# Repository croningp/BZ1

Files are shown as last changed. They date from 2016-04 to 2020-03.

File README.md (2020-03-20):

# BZ-CA

Platform to physically embody cellular-automaton using Belousov-Zhabotinsky
reaction-diffusion chemistry in addressably stirred cells.

## Aims of project
* Create working platform of addressable magnetic stirrers
* Use platform to demonstrate control over cell oscillations
* Control patterns of oscillating cell arrays using machine learning

## Platform
BZ-CA has a working stirrer array. It is also connected to a series of pump to add/remove liquid.

How to build the platform is explained with detail on the manuscript [pre-print](https://chemrxiv.org/articles/A_programmable_chemical_computer_with_memory_and_pattern_recognition/7712564).  

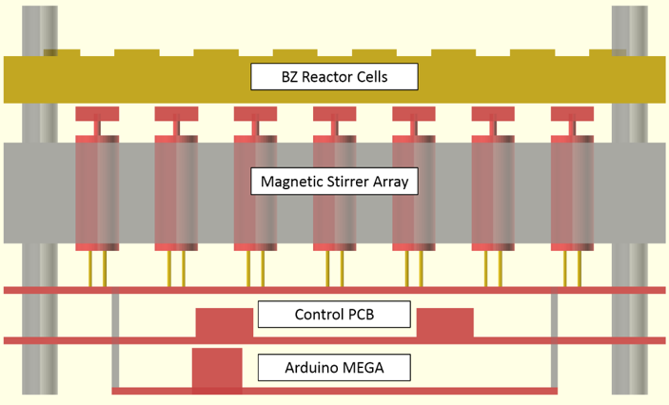
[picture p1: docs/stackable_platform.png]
stackable_platform


This document explains how to build the first iteration of the platform, which is what was used to obtain the results obtained there.
It used custom-made electronics.
The current iteration uses the same hardware and 3D-printed parts, but the electronics are controlled using stacked [Adafruit Motor shields](https://learn.adafruit.com/adafruit-motor-shield-v2-for-arduino).

## Software

The software to control this platform is divided into different files:

* [bzboard.py](software/bzboard/bzboard.py) controls the motors that actuate the stirrers.
* [pumpsctl.py](software/pumpsctl/pumpsctl.py) controls the pumps to add and remove liquid from the platform.
* [firmware](software/firmware/) controls the Arduino scripts to control the 2 arduinos that were actuating the stirrers and the pumps.
* [image processing](software/img_proc) is the implementation of the SVM to classify the oscillations between red and blue.

## Example Code
An example of how to use the bzboard.py code is provided below
and in [initBZ.py](software/initBZ.py):

```python

################################################################
# This script should be used before starting the experiments
# to make sure everything is working and tubes are filled
################################################################

import time

from pumpsctl.pumpsctl import PumpsCtl
from bzboard.bzboard import BZBoard
from img_proc.record_cam import RecordVideo
import os, sys
sys.path.append(os.path.abspath('..'))
from tools.volctl import VolCtl 

v = VolCtl()
b = BZBoard("/dev/ttyACM1")
p = PumpsCtl('/dev/ttyACM0', v)

rv = RecordVideo(10)

waste = {'pump':'P0', 'quantity':75, 'speedIn':50, 'speedOut':50}
water = {'pump':'P4', 'quantity':5, 'speedIn':60, 'speedOut':70}
h2so4 = {'pump':'P2', 'quantity':5, 'speedIn':60, 'speedOut':70}
kbro3 = {'pump':'P5', 'quantity':5, 'speedIn':110, 'speedOut':110}
malonic = {'pump':'P3', 'quantity':5, 'speedIn':60, 'speedOut':70}
water_clean = {'pump':'P4', 'quantity':50, 'speedIn':50, 'speedOut':70}
ferroin = {'pump':'P1', 'quantity':2, 'speedIn':50, 'speedOut':50}

# make sure these 4 pumps are filled, I will test ferroin individually 
p.pump_multiple(water, malonic, kbro3, h2so4,ferroin)
# activate all max speed for 30 second to mix
b.activate_all()
time.sleep(30)
b.disable_all()

rv.record_threaded("test")
time.sleep(10)

p.pump_multiple(water_clean, waste)
p.pump_multiple(waste)
```

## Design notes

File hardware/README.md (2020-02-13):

This folder contains all the designs and stl files of the 3D-printed parts.

All of them were designed with OpenSCAD and printed using a Stratasys Connex 3D-printer, with white material.

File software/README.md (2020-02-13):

This folder contains all the software written to develop this project.

* bzboard contains the python script to actuate as middleman between the firmware and the stirrers. This is the one used by the user to perform experiments.
* pumpsctl is a similar file to bzboard, but in this case to control the liquid pumps.
* img_proc contains all the files used to perform the Computer Vision using a SVM and classify the oscillations between red and blue.
* tools contains two files, one of them to send emails from the platform when a message needs to be sent, and another one to check the volume of the different reactants and the waste bottle.
* firmware contains the Arduino-C code to control both the pumps and the stirrers. 2 different Arduino Mega boards were used, one for each.
* Data Analysis contains a Jupyter Notebook to analyse the dataset used to train the SVM.

All the other python files in this folder were used to directly run experiments.

* initBZ.py should be executed before starting the experiments. It's objective is to check that everything works fine. This must be visually inspected by the user, this script will merely run quickly all the components.
* cleanBZ.py is a script used to clean the area with waste and water.
* main.py is a basic script which will load the BZ medium into the platform, and then drain in. Code here can be injected to execute one experiments.
* automatedBZ.py is the script we used the most, and it will perform all the steps required to perform one experiment.
* experiment_parent.py and randompatter.py are OO implementations of the previous one.
* cellular_automata.py is an attempt of creating a CA using this platform, and it can be used to dynamically actuate the motors based on the visual information from the image processing. Nevertheless, the CA never really worked on this iteration of the platform.

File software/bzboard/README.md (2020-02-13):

bzplatform is the python script to communicate with the arduino and actuate the platform.

in the "patterns" folder there it can be seen all the patterns that we use to input data into our platform.

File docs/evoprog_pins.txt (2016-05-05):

evopin:[pwmshield,pwmpin]
 2:[1, 7]
 3:[1, 6]
 4:[1, 5]
 5:[1, 4]
 6:[1, 3]
 7:[1, 2]
 8:[1, 1]
 9:[1, 0]
14:[0, 4]
15:[0, 5]
16:[0, 6]
17:[0, 7]
24:[0, 8]
26:[0, 9]
28:[0,10]
30:[0,11]
32:[0,12]
34:[0,13]
36:[0,14]
38:[0,15]
42:[1, 8]
44:[1, 9]
46:[1,10]
48:[1,11]
50:[1,12]
52:[1,14]
53:[1,15]
51:[1,13]

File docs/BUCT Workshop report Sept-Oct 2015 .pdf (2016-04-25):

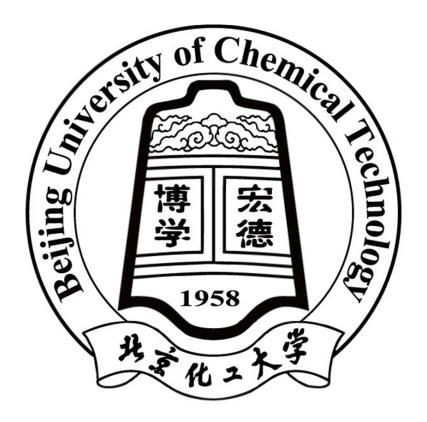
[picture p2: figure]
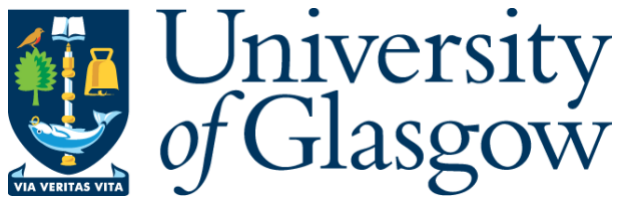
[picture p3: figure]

# Coupling Belousov–Zhabotinsky Oscillations in 3D Reactionware

# October 2015 WORKSHOP REPORT

PREPARED BY

Dr. Geoff Cooper
Kevin Donkers

## Acknowledgements

### Organizers and Participants

Organizers:

■ | School of Chemistry, University of Glasgow, United Kingdom;
■ | International Research Centre for Soft Matter, Beijing University of Chemical Technology, China;
■ | State Key Laboratory of Chemical Resource Engineering, Beijing University of Chemical Technology, China

Moderators:

■ | Prof. Leroy Cronin, University of Glasgow;
■ | Prof. Yu-Fei Song, Beijing University of Chemical Technology

Participants:

Dr. Geoff Cooper, Kevin Donkers, Dr. Chang-Gen Lin, Ze-lin Wang, Wei Zhou, Wen-bo Zhang and Xue-ting Xiong.

## Table of Contents

# Introduction

Three-dimensional (3D) printing (or Additive Manufacturing), which has been widely used in industrial manufacturing to produce prototypes,¹ has gained increasing momentum and popularity over the past decade in various fields such as medicine,² biology,³⁻⁵ millifluidics/microfluidics,⁶⁻⁸ electronics,

9 and pneumatics.¹⁰⁻¹² The key advantage of 3D printing lies in its ease, speed and price of design and manufacturing compared to commercial alternatives. Recently the concept of 3D-printed bespoke reactors, or “reactionware”, for chemical science has been proposed by Cronin et al.¹³⁻ 15 Another advantage of 3D printing is that the designs for a product can be shared online, downloaded, modified and then rapidly reproduced to meet personal demand.

The Belousov-Zhabotinskii (BZ) reaction is one of the most well-known and widely studied oscillating chemical reactions. Although it was first reported in 1958 by B. P. Belousov,¹⁶ it was not widely accepted by the scientific community until the early sixties when more detailed studies had been completed by A. M. Zhabotinskii.¹⁷ The first oscillating reactions of this type were produced by the addition of potassium bromate and citric acid to an acidified solution of cerium IV sulphate. After a short induction period, oscillations in intermediate concentrations are produced by autocatalytic single electron redox reactions involving the metal ion catalyst. The colour of the solution is seen to alternate between clear and pale yellow with a period of a few minutes. This oscillatory behaviour is sustained for several hours during which the substrate, citric acid, is decomposed to produce methanoic acid and carbon dioxide gas. Although all known BZ type oscillating reactions involve potassium bromate as the oxidising agent, the use of several different metal-ion catalysts, organic substrates and acids have been investigated.¹⁸ Oscillations have been successfully obtained using various free metal ions or their complexes, all of which have a single electron couple with a reduction potential of around +1.5 V / SHE.¹⁸

In order to allow visual observation of the oscillations, Fe(phen)2

2+ (ferroin) is often
added to the reaction mixture (or even used as the main metal catalyst) as it has a strong red colouration but is bright blue in its oxidised form, ferrin. There is also a large range of organic substrates that give rise to oscillations in this system, although malonic acid (MA) is the most widely used. The mechanistic details of the cerium catalysed BZ reaction of malonic acid were elucidated in 1972 by Field, Kõrõs and Noyes¹⁹ and supplied an intellectual framework for further investigation of this system. The skeleton FKN mechanism (so named after its discoverers) comprises eleven discrete reactions, but for a general mechanistic description, it is often more useful to simplify the FKN mechanism to a three step sequence often referred to as the Simple Oregonator Model (SOM):
{A} | BrO3
- + 2Br⁻ + 3CH2(COOH)2 + 3H⁺ | 3BrCH(COOH)2 + 3H2O
{B} | 4M⁽x) + BrO3
- + 5H⁺ + CH2(COOH)2 | 4M⁽x+1) + 3H2O + BrCH(COOH)2

{C} | BrCH(COOH)2 + 4M⁽x+1) + 2H2O | 5H⁺ + Br⁻ + 4M⁽x) + 2CO2 + HCOOH

The oscillations of the BZ reaction are sensitive to external physical perturbations and may become complex or show chaotic behaviour under some situations. For example, the period of oscillation is known to vary with temperature.

20 The stirring rate is also important with unstirred systems exhibiting chaotic effects while excessive stirring can totally inhibit oscillations.²¹⁻²²

Given the control over the oscillatory behaviour of BZ reactions and the ability of non-oscillating reaction mixture to be excited by such oscillations researchers have theorised its use in basic computation systems,

23-24 and simulated architectures for its use in Boolean logic gates²⁵ and a binary adder.

26

A model from which compatibility of a system can be tested is a cellular automaton. It consists of an array of cells which change their state based on a fixed set of rules and the states of their surrounding cells in time steps called generations. From a simple initial pattern of cells complex behaviour can quickly emerge out of such a system.²⁷ The concept has been extensively studied and a list of Rules exists on which an automaton can rely and reproduce an expected output e.g. Rule 110:

t=n

t=n+1

Figure 1: Rule 110 – Every group of three cells at time t = n affects the state of the cell centrally below it in the next generation at t = n+1. Blue cell = 1 state, white cell = 0 state.

Constructing cellular automata to conduct Boolean logic operations was proposed and simulated by Adamatzky.

28 Such a system involved using light sensitive catalyst loaded into a gel to control the reaction over a 2D array. Simulation of a 1D cellular automaton using reaction-diffusion chemistry to reproduce Rule 110 and Rule 60 was reported by Scalise and Schulman.

29 However no evidence could be found of a physical experimental system utilising reaction-diffusion chemistry to embody a cellular automaton.

Building on the previous work on reactionware to facilitate rapid production of different reactor designs, we aimed to investigate whether a series of individual ‘cells’ containing the BZ reaction could be controlled to emulate a cellular automaton. To do this we arranged patterns of small wells in a 3D-printed block and varied their size, number and fluidic connectivity while monitoring the BZ oscillations optically. Using the knowledge that stirring / not-stirring will influence the oscillatory behaviours of the BZ reaction cells, we positioned magnetic stirring bars in certain cells (in a pre-determined pattern) to see if the pattern of stirred cells was able to influence / drive the oscillations in a) neighbouring cells or b) the whole system.

# Results and Discussion

Reactionware Design

The basic starting design for the reactionware comprised a monolithic circular block into which a square arena was inset. This was then divided into equal sized square cells by printing walls at equal spacings. The initial experiment was to determine the maximum sized cell that would continue to produce bulk oscillations over the whole cell, rather than break down into sub-cells. To do this a number of different wall configurations were needed, so the reaction container was configured with a grid of grooves in order to accept several different grids / cells sizes.

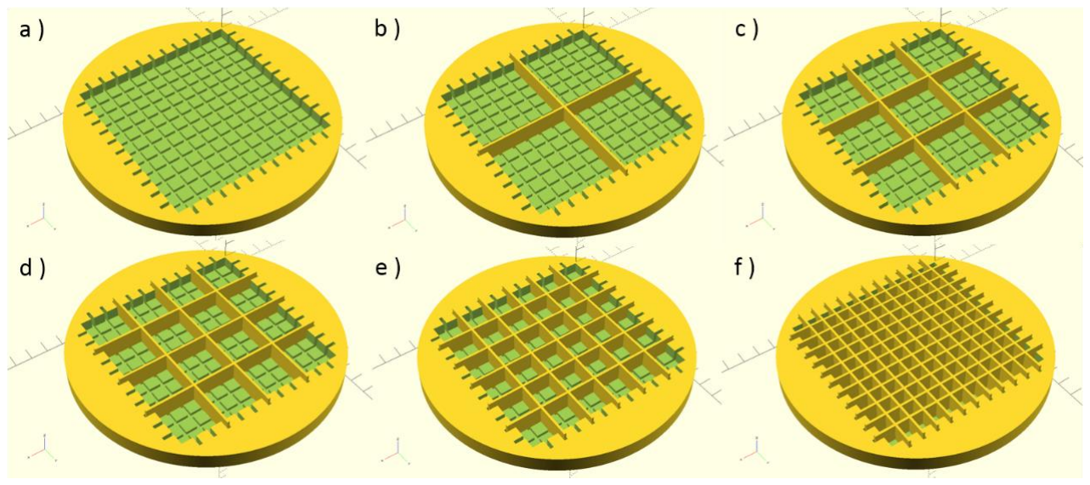
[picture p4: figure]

Figure 2: Reactionware of 110x110x5 mm arena divided into an array of 12x12 with grooves to allow for multiple configurations of cells using different wall insets: a) 1x1; b) 2x2; c) 3x3; d) 4x4; e) 6x6; f) 12x12.

A circular base structure was used to minimise the warping seen when printing straight lines/square structures on the 3D-printer. An array of 12x12 cells was used to allow for six different arrays: 1x1, 2x2, 3x3, 4x4, 6x6 & 12x12.

A similar design with a 5x5 array of 8x8x5 mm cells was also printed and used extensively in these experiments.

CAD models were designed using OpenSCAD software. A script was written allowing one to define the number and dimensions of cells and the dimensions of the overall reactor, as well as the number of walls and dimensions of channels between cells, if required.

BZ Reaction Parameters and Control

In order to follow the BZ oscillations optically, we chose to use a ferroin catalysed system. This has two advantages: 1) ferroin provides a great blue vs. red colour change that is very easy to distinguish optically; 2) when ferroin is used as an indicator along with another metal salt catalyst, the BZ oscillations often become more complex, as the ferroin driven oscillations can become de-coupled. This de-coupling would make following the oscillations more difficult.

In order to ensure oscillations were visible in the reactionware, the BZ systems were first prepared in bulk and stirred, to allow the oscillations to initiate. Once initiated, the solution was poured into the reactionware and distributed over all the available reaction cells. Where stirring was to be used, the stirrer bars were placed in the cells from the beginning of the reaction but stirring was not started until ca. 5 minutes had elapsed. We found that he BZ oscillations were short-lived / supressed in the absence of stirring in the cells, although some oscillations did still develop. Where oscillations developed in the reactionware, they typically had a recycle time of between 30 seconds and 2 minutes.

To take advantage of this, the whole reactionware block was placed on a magnetic stirring plate and magnetic stirring beads (3x5mm) were placed in some of the cells. This way the stirring could be turned on and those cells stirred, causing them to begin oscillating. The pattern of beads in the reactionware grid could then impart a pattern on the chemical system, where stirred cells were more likely to oscillate.

The ideal situation for unconnected cells, where pattern enforcement works might look like this (1 denotes a stirred cell while 0 is unstirred):

1 | 0 | 1 | 0 | 1
0 | 1 | 0 | 1 | 0
1 | 0 | 1 | 0 | 1
0 | 1 | 0 | 1 | 0
1 | 0 | 1 | 0 | 1
| | T=0
1 | 0 | 1 | 0 | 1
0 | 1 | 0 | 1 | 0
1 | 0 | 1 | 0 | 1
0 | 1 | 0 | 1 | 0
1 | 0 | 1 | 0 | 1
T=n (oscillation)
1 | 0 | 1 | 0 | 1
0 | 1 | 0 | 1 | 0
1 | 0 | 1 | 0 | 1
0 | 1 | 0 | 1 | 0
1 | 0 | 1 | 0 | 1
… etc

The ideal situation for connected cells, where pattern enforcement works and drives neighbours might look like this (1 denotes a stirred cell while 0 is unstirred):

1 | 0 | 1 | 0 | 1
0 | 1 | 0 | 1 | 0
1 | 0 | 1 | 0 | 1
0 | 1 | 0 | 1 | 0
1 | 0 | 1 | 0 | 1
T=0
1 | 0 | 1 | 0 | 1
0 | 1 | 0 | 1 | 0
1 | 0 | 1 | 0 | 1
0 | 1 | 0 | 1 | 0
1 | 0 | 1 | 0 | 1
T=n (oscillation)
1 | 0 | 1 | 0 | 1
0 | 1 | 0 | 1 | 0
1 | 0 | 1 | 0 | 1
0 | 1 | 0 | 1 | 0
1 | 0 | 1 | 0 | 1
response
1 | 0 | 1 | 0 | 1
0 | 1 | 0 | 1 | 0
1 | 0 | 1 | 0 | 1
0 | 1 | 0 | 1 | 0
1 | 0 | 1 | 0 | 1
| | … etc

Initial Data Analysis and Results

The initial experiments aimed to establish the minimum size of unconnected cell which would support a stable oscillation. Using the two-part design of base and grid, a 85x85x5 mm reactionware arena was printed with a dividing grid that gave a 5x5 pattern of (approx.) 15x15x5 mm cells without any channels connecting them. 45 ml of already oscillating BZ reaction solution was added (recipe in experimental section) and timelapse images were acquired for two hours. Individual oscillations with a period of ~45 seconds were observed in the bulk and mostly the cells remained in phase (there may have been significant leakage and therefore fluidic connection between the cells). The oscillations became weaker and bulk changes were no longer observed after 10 minutes. Instead, the cells were seen to break down into chaotic regions, as might be expected in an unstirred system.

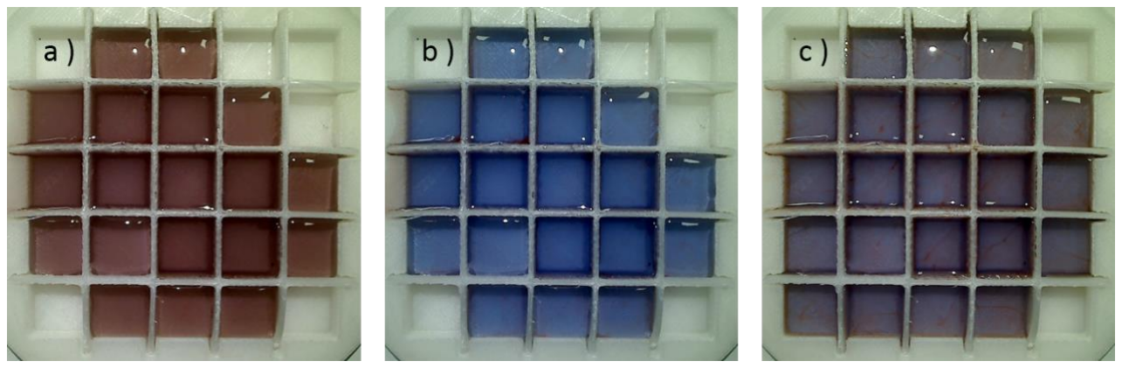
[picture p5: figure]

Figure 3: a) & b) Bulk oscillations with all the cells in synch. c) Cells no longer bulk oscillate, instead oscillating with chaotic structures seen as red streaks and spots.

Realising that the individual cells would not oscillate for sufficiently long without stirring, further experiments were carried out on a stirring plate with magnetic stirring beads placed in some wells. Reactionware with a 110x110x5 mm arena with an 11x11 grid of equally spaced grooves allowed different dividers to be used giving either a 12x12 or 6x6 grid of cells. Using a 6x6 grid, cells were (approx.) 12x12x5 mm and the grooved base meant that the fit of the grid was tight – cell to cell leakage was minimised.

A standard BZ mixture was added and stirring bars were added in the pattern: {000000,000000,111111,000000,000000,000000}. Initially bulk oscillations were observed over the whole grid, but after a few cycles, only those cells which were being
stirred | showed | clear | oscillations. | The | pattern | was | changed | to
{111111,000000,111111,000000,000000,000000} by the addition of stirring beads and within a few seconds, the newly stirred cells also began to oscillate cleanly. Removal of beads to give the pattern {111000,000000,111111,000000,000000,000000} resulted in the three cells that were no longer stirred oscillating for 3-4 more cycles and then breaking down. This clearly shows that control of individual oscillators (stopping and starting) is possible with stirring.

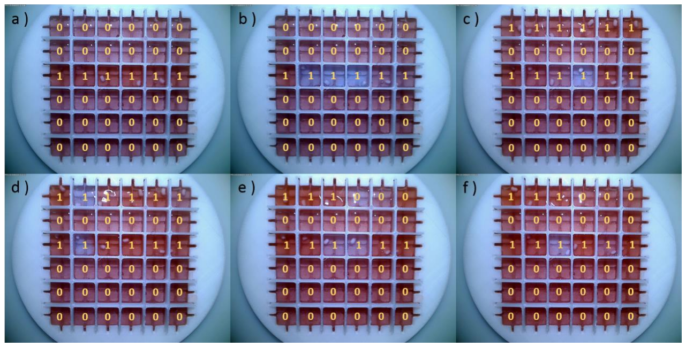
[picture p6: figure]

Figure 4: a) Initial uniform bulk oscillation. b) Only stirred cells oscillating. c) Stirrers placed in initially non-oscillating cells. d) Stirrers initiate oscillations in cells. e) Stirrers removed but oscillations continue for a few cycles. f) Only stirred cells continue to oscillate.

Lifting the grid slightly above the bottom of the base in the same reactionware allowed the cells to be fluidically connected. Applying a stirring pattern of {111111,000000,101010,000000,111111,000000}, the stirred cells were seen to oscillate clearly and cells with at least two stirred neighbours, while not oscillating as convincingly, were certainly influenced. This is evident in the timelapse video but is not clearly demonstrable with still images.

In the above experiment, the cells were probably too large to be influenced by just one oscillating neighbour. To solve this, we tested smaller wells. Dividing the same arena into a 12x12 grid resulted in cells that were too small to be imaged easily due to shadowing from the walls.

After some testing, the design that gave the best consistent results was a 55x55x5 mm arena divided into 5x5 grid of square wells (approx. 9x9x5 mm) where the barriers had large channels cut out from the top (to prevent stirrer bars from travelling between cells). Applying the stirring pattern {10101,01010,10101,01010,10101} produced excellent oscillations in the stirred cells which were clearly coupled into the neighbouring unstirred cells.

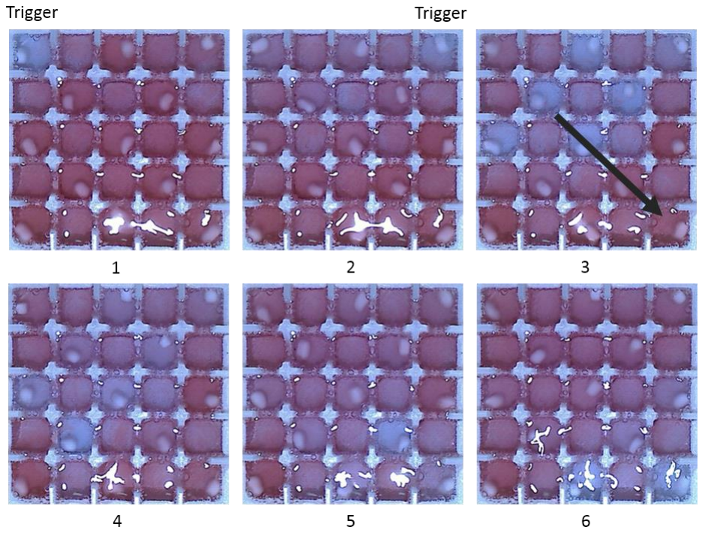
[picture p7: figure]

Figure 5: Oscillations eventually coordinated into two triggers in two corners initiating a chemical wave which travelled from one corner to another (in direction of arrow). This behaviour repeated for several cycles until oscillations fell out of phase with each other.

Stirring was stopped and oscillations continued for 3-4 more cycles before dying out. Once stirring was restarted oscillations restarted instantaneously as before.

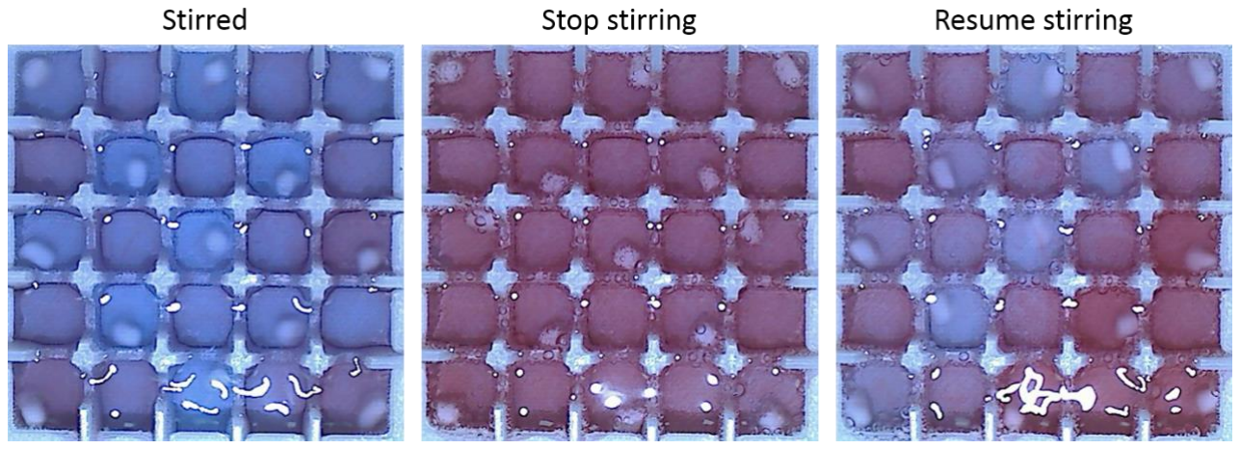
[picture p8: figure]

Figure 6: Oscillations could be stopped by switching the stirring off and restarted almost immediately by switching the stirring back on.

Two more 5x5 bases were printed with channels in the walls to allow fluidic connections between the cells. However on this day it appeared that the BZ solution was not oscillating well so no oscillation patterns were observed. For each base an inset with different channel height (from the bottom of the cell) was used. A height of 2mm led to stirrer beads hopping between cells. 3mm proved sufficient to contain the stirrer beads.

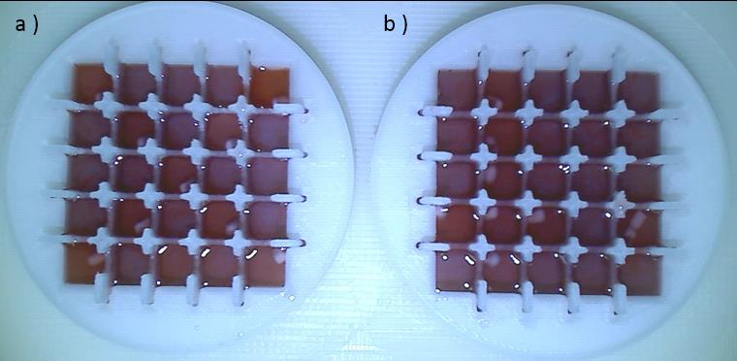
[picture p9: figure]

Figure 7: No oscillations observed. a) {10001,01010,00100,01010,10001}. b) {01000,01000,01000,11111,01000}

A monolithic reactor was designed and printed which used circular cells instead of square ones. This guaranteed that the only fluidic connection between cells was through the cutout/printed channels and utilised the printer’s accuracy for printing circular structures.

Into a reactor of 6x6 cells of 8 mm diameter and 5 mm depth channels were cut out to allow fluidic connection. Three experiments were carried out with the following configurations:

{101010,010101,101010,010101,101010,010101}

Circular cells produced travelling oscillations as seen in the previous experiment but the cells did not fully bulk oscillate. In addition there were fewer repeated oscillation patterns than the previous experiment. This would imply that the cells were too large to fully bulk oscillate.

{111111,000000,000000,111111,000000,000000}

Apart from the first few whole array oscillations there were no sustained oscillations in any of the cells, stirred or not. There were however flow like patterns in the unstirred cells between the stirred cells. The ‘direction’ of flow was maintained for the duration of the experiment. It is unclear whether this was physical flow of material or the illusion of flow due to oscillation pattern of the reaction.

{000000,011110,010010,010010,011110,000000}

Less than ten full array oscillations were observed before settling to non-oscillating state. The central four, unstirred cells appeared to approach oscillation after this period but no full oscillations were observed.

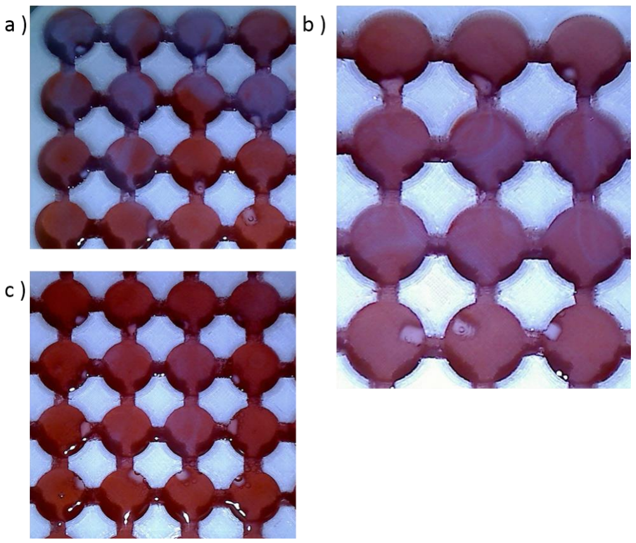
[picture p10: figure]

Figure 8: a){101010,010101,101010,010101,101010,010101} pattern displaying oscillations but remained structured within the cells. b) {111111,00000,000000,111111,000000,000000} pattern displaying no oscillations but flow patterns. c) {000000,011110,010010,010010,011110,000000} showing no sustained oscillations.

The final experiment was used to try the idea of a gravity fed cascade of BZ reaction to see whether oscillations could travel while the reaction mixture was flowing. The following figure depicts the CAD drawing which was 3D printed for use as a cascade:

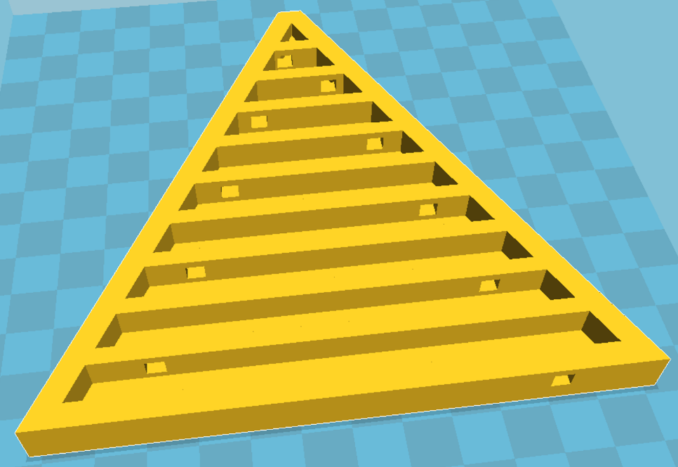
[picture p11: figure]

Figure 9: Cascade of ten levels with holes connecting each one to the next. Reactions fed in from pointed top.

It consisted of ten layers within a triangular cascade, where holes in alternate ends of each layer allowed fluid to flow along each layer. Reaction mixture was fed in from the top via a reservoir and collected out of the bottom into a beaker. A glass facing was glued onto the front to allow the colour of the oscillating mixture to be videoed.

Once a reaction mixture was determined to be oscillating, about half was poured into the top reservoir and allowed to flow through and collected in the beaker. The other half was left to stir on a stirrer plate. Before the top reservoir emptied completely the other half of the mixture was added. This was repeated by hand for about 20 minutes.

It was found that oscillations could be observed which travelled from their point of origin in the top reservoir and travelled through the cascade. The rate of flow had two important effects on observing oscillations in the cascade:

1. High flow meant that there was good fluidic connection between the layers of the cascade and any oscillations would travel through all the layers. However this led to shorter periods of time between reservoir refills, which interrupted any oscillation if a refill coincided with an oscillation.
2. Low flow would mean that an oscillation would definitely occur in the time between refills. However this also led to poor fluidic connection between layers and any oscillations which did occur only travelled as far as the first 2-3 layers.

An intermediate flow was found by using a bulldog clip to control the flow through the tubing connecting the top of the cascade and the reservoir. Doing so led to video of footage of several oscillations which travelled through the cascade despite the physical flow of reaction mixture. Improvements would include automation of refilling with pumps and printing with hydrophilic polymer such as polylactic acid to fully fill cascade.

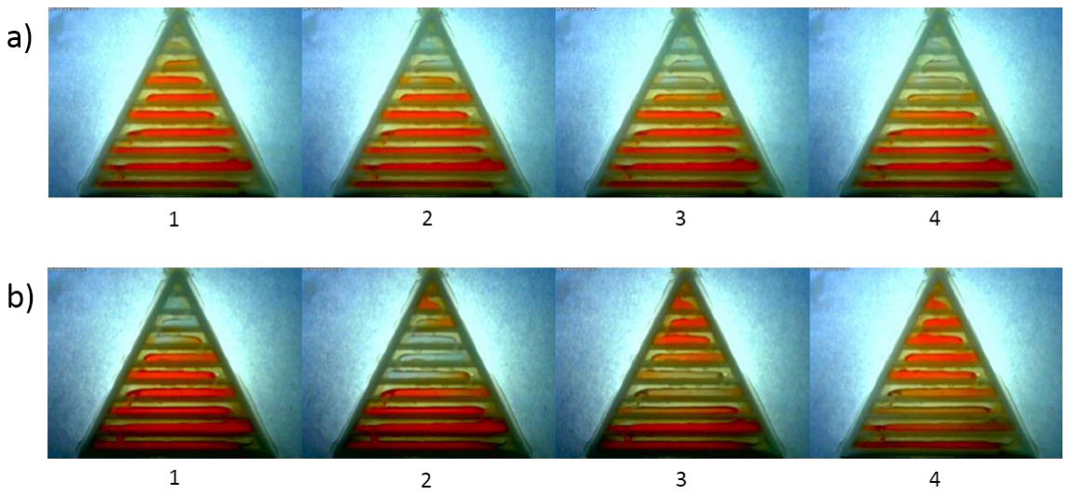
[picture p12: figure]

Figure 10: a) Low flowrate led to confinement of oscillation in first three layers. b) Median flowrate led to oscillation travelling through most of the layers of the cascade. High flowrate led to interruption of oscillation before it could be recorded.

## Experimental Section

All chemicals were purchased from Alfa Aesar or Beijing Chemical Works, and used as received.

3D Printing: 3D printing was achieved on Airwolf HD2x 3D printer, using Poly-propylene (PP) supplied by Barnes Plastic Welding Equipment Ltd, Blackburn, UK. To prevent corners from lifting due to warping, PP was printed on a 5 mm thick PP sheet

Design Software: 3D-printed reactors used in this work were designed on OpenSCAD computer aided design software (http://www.openscad.org/), and were translated into 3D printer instruction files using open source Cura15 (powered by Ultimaker) software (https://ultimaker.com/en/products/cura-software).

Reactionware: The designs for each type of reactionware were saved in a .scad script to allow for easy changing of reactor parameters. The following files and tables of parameters were used to produce all the reactionware depicted in this report.

GC_BZ-3D_square_in_circular_grooves_with_grid_and_channels.scad

KD_BZ_3d_circle_cell_monolith.scad

WZL_BZ-3D_Trapezoid_cascade.scad

BZ Reaction Recipe: We chose to use a ferroin catalysed BZ system as this allows fairly ‘simple’ oscillations which can be easily followed optically. The following recipe was used in the experiments:
- 20ml of 1M Malonic Acid in water
- 20ml of 0.5M KBrO3 in 1M H2SO4
- 9ml of 1M H2SO4
- 1ml ferroin solution (0.025M, purchased as solution)
- Made up to total 90ml with 39ml water
Square | nx/y | cx/y | cz | base | edge | gw | gz | gh | shim | raise | prop
Figure 1 | 12 | 9 | 5 | 3 | 10 | 2 | 2 | 6 | 0.3 | | 0.2
Figure 3 | 5 | 16 | 5 | 3 | 10 | 2 | 2 | 6 | 0.3 | | 0.2
Figure 4 | 6 | 18 | 5 | 3 | 10 | 2 | 2 | 6 | 0.3 | | 0.2
Figure 5 | 5 | 11 | 5 | 3 | 10 | 2 | 2 | 6 | 0.3 | | 0.2
Figure 7 (a) | 5 | 11 | 5 | 3 | 10 | 2 | 2 | 6 | 0.3 | 2 | 0.2
Figure 7 (b) | 5 | 11 | 5 | 3 | 10 | 2 | 2 | 6 | 0.3 | 3 | 0.2
Circular | nx/y | cd | ch | gd | gh | gl | edge | base
Figure 8 | 6 | 15 | 8 | 3 | 3 | 3 | 3 | 4
Cascade | lay | Hl | h | edge | gap | base | cw | cd | tcw | tcp | in
Figure 9 | 10 | 7.5 | 7.5 | 5 | 3.5 | 3 | 4 | 4 | 2 | 2 | 2

The experiments were initiated by adding the potassium bromate solution to the other reagents pre-mixed in a beaker. This was stirred for a few minutes to allow bulk oscillations to initiate before being added to the reactionware container.
Initial concentrations of the reagents were as follows:
- Malonic Acid | 0.222M
- H2SO4 | 0.322M
- KBrO3 | 0.111M
- Ferroin | 2.8x10⁻⁴M

Imaging: The oscillations were imaged using a Logitech QuickCam Pro 9000 webcam (at 1600x1200px, 24bit) running 1second timelapse with iSpy Connect software. In each experiment, the reactionware was illuminated from above using an LED torch running from a continuous supply to ensure constant output level.

# Conclusion

Image analysis and mapping of the oscillations was not within the scope of the workshop and this work is ongoing. Based on the workshop data, the following statements can be made:

Stirring can be used to control individual cells. While cells that were not stirred did sometimes oscillate 3-4 times after initiation, the oscillations were not sustained further, even when the whole arena was used (no divisions). Stirred cells showed sustained oscillation (up to 1.5 hours) and previously unstirred cells could be re-started to oscillate if stirred.

Fluid connectivity played a crucial role in propagation of excitations. Hydrophobicity of PP structures caused poor fluidic connection between cells connected by channels with diameters less than ~3 mm. Even when a fluidic connection could be seen chemical excitations did not appear to propagate for such narrow channels. The hydrophobicity of PP also prevented the channels in the cascade from fully filling. This could be mitigated by using hydrophobic polymers such as polylactic acid (PLA).

Oscillating cells could initiate oscillations in neighbouring cells if fluidically connected. The unstirred cells would remain dormant as an excitable medium and oscillate once initiated by a neighbouring oscillation. As seen in figures 5 & 6 cells over a whole array can couple their oscillations to produce collective oscillations and travelling chemical wavefronts.

Future work will involve the following:

Image analysis of existing and future video data. The videos/image stacks must be analysed to extract colour change data from the cells and assign numerical values to stages of the oscillations. This would allow us to reduce the cells to binary arrays and allow tracking of oscillations to determine relationships, if any, between stirred and unstirred cells, and the arrays as a whole.

From this pattern recognition algorithms could be used. This would be important for determining whether such an array of reaction-diffusion medium could act as a cellular automaton.

An obvious continuation of the work which will be carried out in the Cronin Lab at Glasgow will be to build a reactionware system where each cell can be stirred individually. This will allow the pattern of stirred cells to be stopped / started / modified in real time and the effect of this on the oscillatory behaviour to be followed. It may even be possible to implement some image recognition and feedback, such that stirring can be used to enforce a pattern.

# References

1. D. Dimitrov, K. Schreve, N. de Beer, Rapid prototyping J. 2006, 12, 136-147.
2. F. Rengier, A. Mehndiratta, H. von Tengg-Kobligk, C. M. Zechmann, R. Unterhin-ninghofen, H.-U. Kauczor, F. L. Giesel, Int. J. Comput. Ass. Rad. 2010, 5, 335-341.
3. S. J. Hollister, Nat. Mater. 2005, 4, 518-524.
4. R. A. Barry, R. F. Shepherd, J. N. Hanson, R. G. Nuzzo, P. Wiltzius, J. A. Lewis, Adv. Mater. 2009, 21, 2407-2410.
5. S. Hong, D. Sycks, H. F. Chan, S. Lin, G. P. Lopez, F. Guilak, K. W. Leong, X. Zhao, Adv. Mater. 2015, 27, 4035-4040.
6. J. S. Mathieson, M. H. Rosnes, V. Sans, P. J. Kitson, L. Cronin, Beilstein J. Nanotechnol. 2013, 4, 285-291.
7. V. Dragone, V. Sans, M. H. Rosnes, P. J. Kitson, L. Cronin, Beilstein J. Org. Chem. 2013, 9, 951-959.
8. P. J. Kitson, M. H. Rosnes, V. Sans, V. Dragone, L. Cronin, Lab Chip 2012, 12, 3267-3271.
9. B. Y. Ahn, E. B. Duoss, M. J. Motala, X. Y. Guo, S. I. Park, Y. J. Xiong, J. Yoon, R. G. Nuzzo, J. A. Rogers, J. A. Lewis, Science 2009, 323, 1590-1593.
10. T. Hasegawa, K. Nakashima, F. Omatsu, K. Ikuta, Sens. Actuators, A 2008, 143, 390-398.
11. F. Ilievski, A. D. Mazzeo, R. F. Shepherd, X. Chen, G. M. Whitesides, Angew. Chem. Int. Ed. 2011, 123, 1930-1935.
12. S. A. Morin, R. F. Shepherd, S. W. Kwok, A. A. Stokes, A. Nemiroski, G. M. Whitesides, Science 2012, 337, 828-832.
13. M. D. Symes, P. J. Kitson, J. Yan, C. J. Richmond, G. J. T. Cooper, R. W. Bowman, T. Vilbrandt, L. Cronin, Nat. Chem. 2012, 4, 349-354.
14. P. J. Kitson, M. D. Symes, V. Dragone, L. Cronin, Chem. Sci. 2013, 4, 3099-3103.
15. P. J. Kitson, R. J. Marshall, D.-L. Long, R. S. Forgan, L. Cronin, Angew. Chem. Int. Ed. 2014, 53, 12723-12728.
16. B. Belousov, Sbornik Referatov po Radiatsonni Meditsine, Medgiz, Moscow (1958)
17. A. M. Zhabotinskii, Biofizika, 1964, 9, 306.

18. R. J. Field, Oscillations and Travelling Waves in Chemical Systems, John Wiley & Sons (1985)
19. R. J. Field & R. M. Noyes, J. Chem. Phys., 1974, 60(5), 1877.
20. S. Pullela, Phys. Chem. Chem. Phys., 2009, 11(21), 4236.
21. M.J. Blandamer. & D. L. Roberts, J. Chem. Soc. Faraday Trans. I, 1977, 73, 1636.
22. K. Bar-Eli, J. Phys. Chem., 1985, 89, 2852.
23. A. Adamatzky, Chaos Solitons & Fractals, 2004, 21(5), 1259-1264.
24. A. Adamatzky, B. De Lacy Castillo & L. Bull, Int. J. Bifurcation & Chaos, 2011, 21(7), 1997-1986.
25. A. Adamatzky et al., BioSys., 2012, 109(1), 72-77.
26. G. Zhang et al., J. Chem. Phys, 2012, 136(16), 164108.
27. S. Wolfram, Caltech Preprint, 1982.
28. C. Stone, R. Toth, B. De Lacy Costello, L. Bull & A. Adamatzky, Proc. 10th Int Conf. Parallel Problem Solving from Nature: 2008, 2008, 579-588.
29. D. Scalise & R. Shulman, Natural Comp., 2015, 1-18.

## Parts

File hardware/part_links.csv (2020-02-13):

Part | url | Purchase url
Motors | - | See SI for the exact specs | they were bought from alixpress but the link is dead now | but very similar motors with same specs can be found
PWM shield | https://learn.adafruit.com/adafruit-motor-shield-v2-for-arduino
Stackable headers | - | https://shop.pimoroni.com/products/arduino-stackable-header-6-pin
Darlington transistor arrays | http://www.ti.com/lit/ds/symlink/uln2803a.pdf | Ask So
Arduino Mega | https://www.arduino.cc/en/Main/ArduinoBoardMega
Magnets | - | http://www.first4magnets.com/circular-disc-rod-magnets-c34/2mm-dia-x-2mm-thick-n42sh-neodymium-magnet-0-15kg-pull-p3327

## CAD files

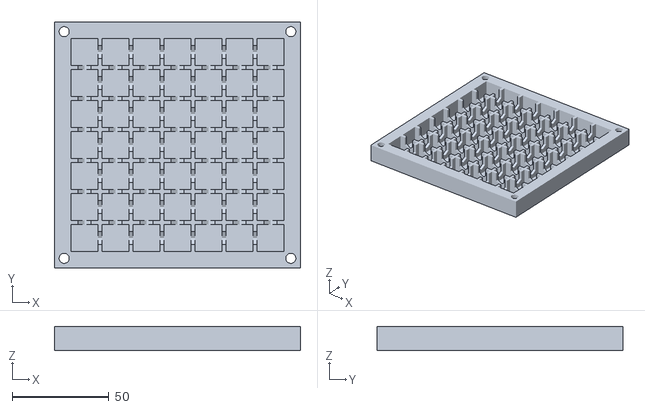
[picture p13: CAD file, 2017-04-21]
hardware/arena/bz_ca - arena Bigger.stl
127.0 x 127.0 x 12.5

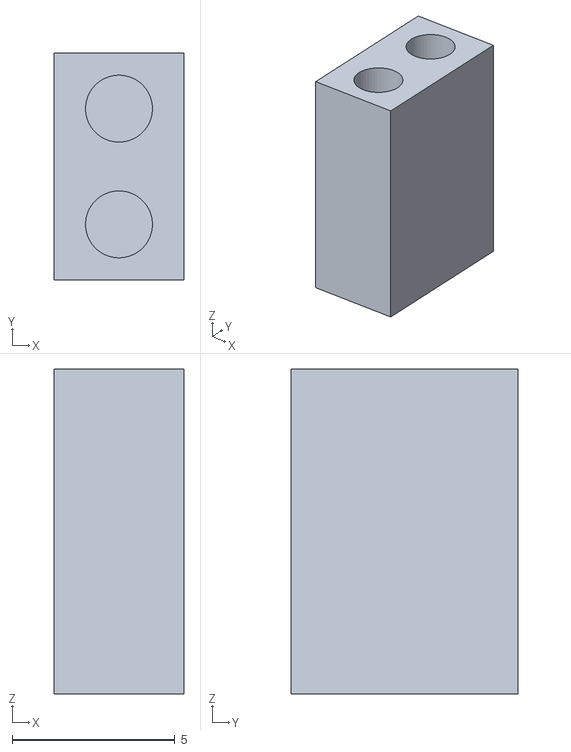
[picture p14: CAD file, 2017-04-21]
hardware/magnet_mount/bz_ca - magnet_holder bigger.stl
4.00 x 7.00 x 10.0

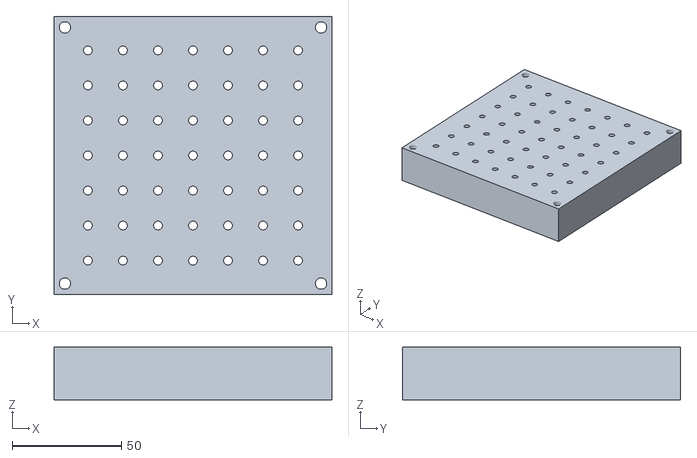
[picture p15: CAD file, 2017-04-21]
hardware/motor_mount/motor_mount.stl
127.0 x 127.0 x 24.0

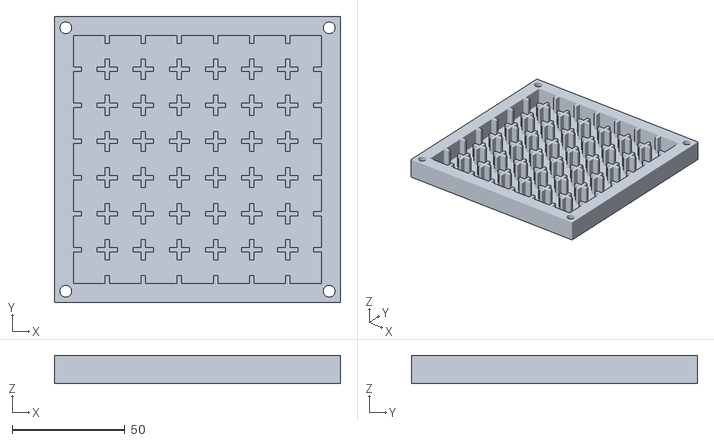
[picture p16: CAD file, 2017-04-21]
hardware/arena/bz_ca - arena Bigger minimal barriers.stl
127.0 x 127.0 x 12.5

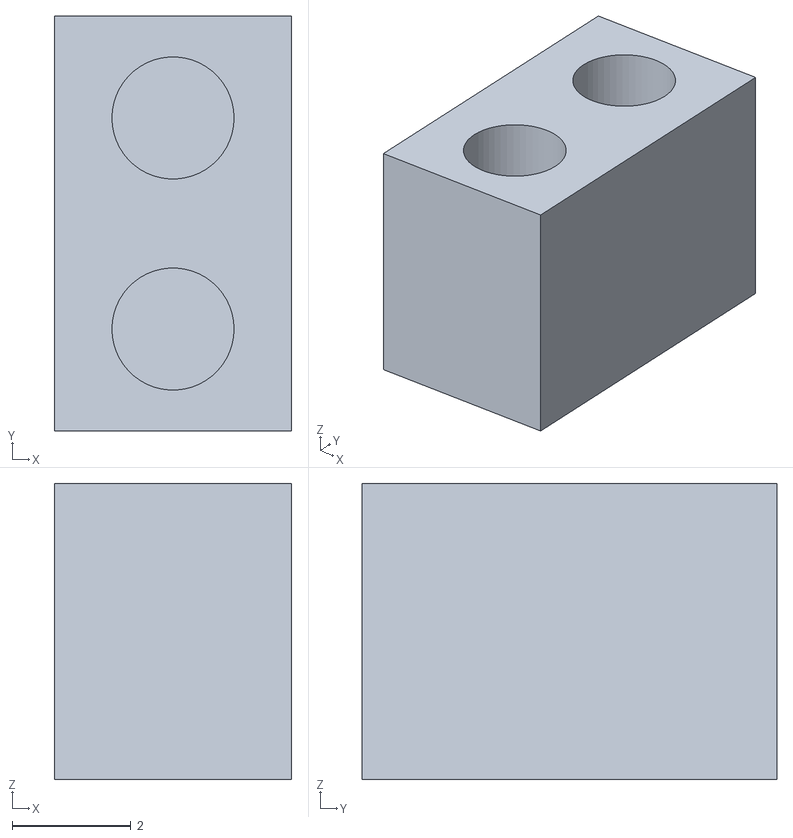
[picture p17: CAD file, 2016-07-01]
hardware/magnet_mount/bz_ca - magnet_holder.stl
4.00 x 7.00 x 5.00

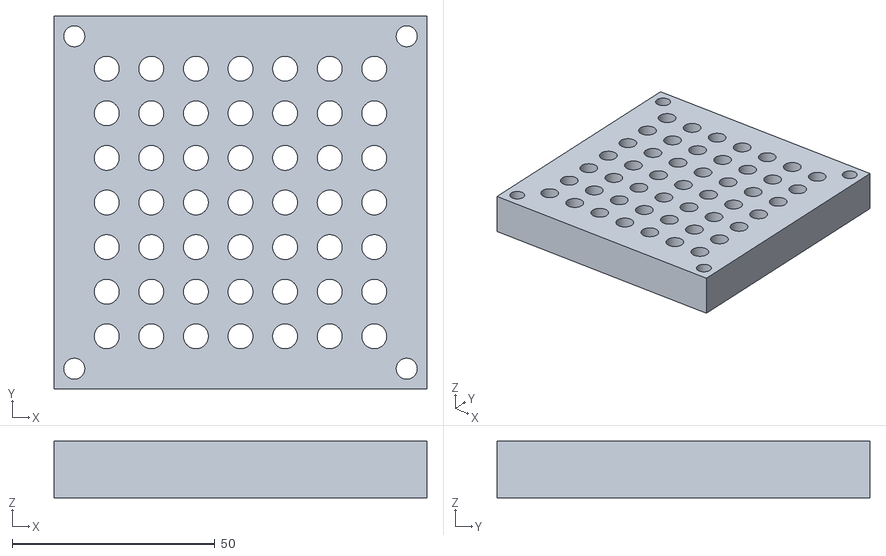
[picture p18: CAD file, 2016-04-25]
hardware/motor_mount/bz_ca - motor_mount.stl
92.0 x 92.0 x 14.0

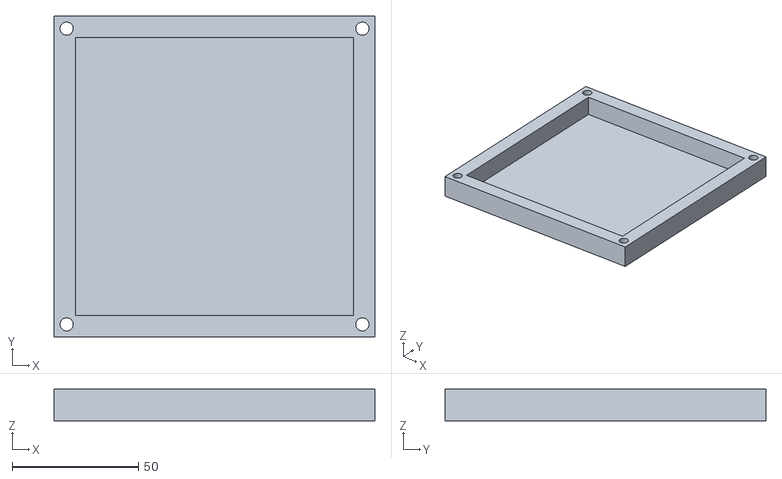
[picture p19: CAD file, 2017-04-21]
hardware/arena/bz_ca - arena Bigger NO barriers.stl
127.0 x 127.0 x 12.5

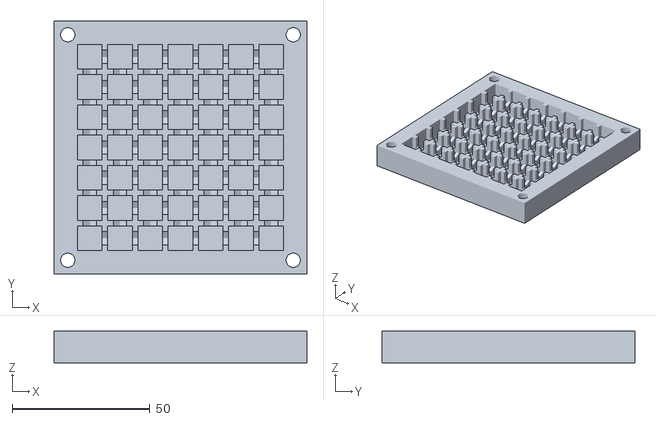
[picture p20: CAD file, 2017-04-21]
hardware/arena/bz_ca - arena - deep.stl
92.0 x 92.0 x 11.5

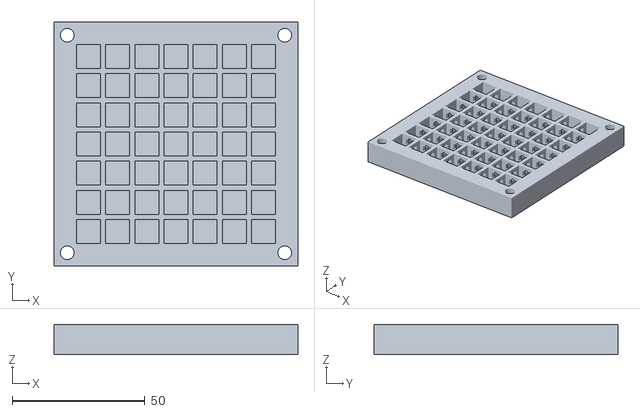
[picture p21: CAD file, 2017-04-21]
hardware/arena/bz_ca - arena - holes.stl
92.0 x 92.0 x 11.5

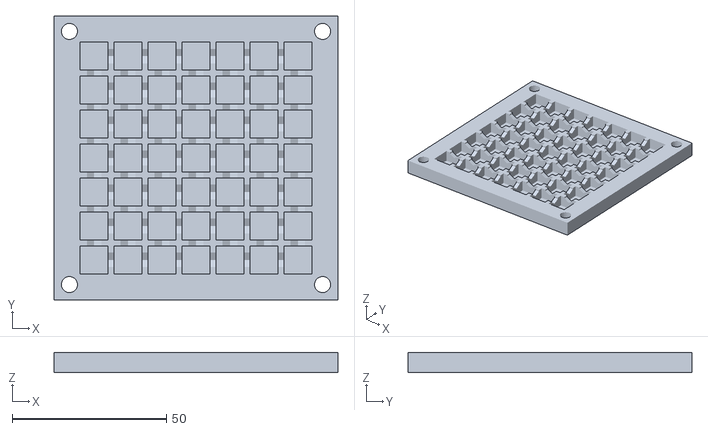
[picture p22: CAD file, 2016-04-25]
hardware/arena/bz_ca - arena.stl
92.0 x 92.0 x 6.50

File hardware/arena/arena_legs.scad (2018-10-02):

leg();
translate([20,0,0])leg();
translate([20,20,0])leg();
translate([0,20,0])leg();

translate([0,40,0])spacers();
translate([20,40,0])spacers();
translate([20,60,0])spacers();
translate([0,60,0])spacers();


module leg() {
    cube([10,10,30]);
    translate([5,5,30])cylinder(h=60, d=4.5, $fn=20);
}

module spacers() {

    difference() {
        cube([10,10,13.5]);
        translate([5,5,-1])cylinder(h=20, d=7, $fn=20);
    }
}

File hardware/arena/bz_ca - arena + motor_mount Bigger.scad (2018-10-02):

//KD_BZ-3D_square_in_square+grid+channels+stirrer_grid.scad
//08/02/2016    Kevin Donkers, Cronin Group, University of Glasgow
//OpenSCAD file creating a 3D model of a square arena for conducting reaction-diffusion chemistry as part of the BZ-3D workshop in BUCT, Beijing, China.
//Arena contains cells divided by walls with channels
//A holder for a matrix of motors can be modelled too (optional)
//All values in mm.

//What are we printing? #
// 0 = show everything ;)
// 1 = base only
// 2 = grid only, no channels
// 3 = grid only, with tapered channels
// 4 = show none of the base

baseprint = 0;

//Stirrer matrix?
// 0 = hide stirrer matrix
// 1 = show stirrer matrix
// 2 = show stirrer matrix new size holes

stirrer = 0;

// drain = 0 no drain, drain = 1 drain
drain = 1;

// clip = 0 no tubbing clip, clip = 1 yes
clip = 1;

//Cell dimensions

nx = 7;     //number of cells in x
ny = 7;     //number of cells in y
cx = 16;     //cell width
cy = 16;     //cell length
cz = 11;     //cell depth

//Arena total size is (nx*cx)x(ny*cy) 
//Cells are (cx-0.5gw)x(cy-0.5gw)

//Base and edge thicknesses

base = 1.5;
edge = 15;

//Equidistant groove depth and width

gw = 2;     //width
gz = 0;     //depth
gh = 0;     //height above cell edge

shim = 0.0;     //narrowing wrt grooves
extend = 0;   //extension of grooves into sides
raise = -2;      //height of channels from bottom of cell [mm]
prop = 0.5;     //propoprtion of cell wall to have open as channel

//Stirrer motor parameters

md = 4;     //motor top sleeve diameter
mx = 12.05; //motor x width
my = 10.05; //motor y width
mz = 24;    //motor length

//Bolt hole paramters

boltd = 5.2;  //bolt diameter
bolte = 5;  //distance from edge

//Calculate arena dimensions

ax = nx*cx;
ay = ny*cy;
az = cz + gz;

//Calculate block dimensions

bd = sqrt((ax*ax+ay*ay))+edge;   //diameter
bz = az + base;     //depth


//clip attachment for tubing
module clip(){
    side = ax+edge;
    hs = side/2;
    difference() {
        translate([20,6,0])cube([side-40, (edge/2)-0.5, 15]);
        translate([hs-32,30,-2])rotate([65,0,0])cylinder(h=50,d=6, $fn=20);
        translate([hs,30,-2])rotate([65,0,0])cylinder(h=50,d=6, $fn=20);
        translate([hs-16,30,-2])rotate([65,0,0])cylinder(h=50,d=6, $fn=20);
        translate([hs+16,30,-2])rotate([65,0,0])cylinder(h=50,d=6, $fn=20);
        translate([hs+32,30,-2])rotate([65,0,0])cylinder(h=50,d=6, $fn=20);
    }
}

if (clip==1){
rotate([0,0,-90])translate([-20+edge/2-(ax+edge)+20, -6+(-edge/2)+1.5, bz])clip();
}


//Base
if (baseprint==1 || baseprint==0) {
difference() {
    //Create block
    union() {
        translate([-edge/2,-edge/2,0])
        cube([ax+edge,ay+edge,bz],false);
        if(drain==1) {
            translate([-base-1,ax/2,0])
            cube([10,10,4],true);
        }
    }
    //Subtract arena
    translate([(0.5*gw),(0.5*gw),base])
    cube([(ax-gw),(ay-gw),(az+1)],false);
    //Subtract bolt holes
    if (stirrer==1||stirrer==0||stirrer==2){
        translate([-edge/2+bolte,-edge/2+bolte,-1])
        cylinder(h=bz+2,d=boltd,$fn=50);
        translate([ax+edge/2-bolte,-edge/2+bolte,-1])
        cylinder(h=bz+2,d=boltd,$fn=50);     
        translate([-edge/2+bolte,ay+edge/2-bolte,-1])
        cylinder(h=bz+2,d=boltd,$fn=50);
        translate([ax+edge/2-bolte,ay+edge/2-bolte,-1])
        cylinder(h=bz+2,d=boltd,$fn=50);
        }
    if (drain==1) {
        rotate([0,90,0])
        translate([-base-1,ax/2,-(0.5+edge/2)])
        cylinder(h=2+(edge/2), r1=3, r2=2,$fn=50);
    }
}
} 


//Walls
/*
if (baseprint==2 || baseprint==3  ||baseprint==0) {
union() {
    //Build X grid walls
    if (nx>1) {
        translate([cx-(gw*0.5)+shim,-(extend-shim),(base)])
        cube([gw-(2*shim),ay+((extend-shim)*2),(cz/2)])  ;
    for (i=[2:(nx-1)]) {
        if (i<nx) {
        translate([(i*cx)-(gw*0.5)+(shim),-(extend-shim),(base)])
        cube([gw-(2*shim),ay+((extend-shim)*2),(cz/2)]);
    }}};
    //Build Y grid walls 
    if (ny>1) { 
        translate([-(extend-shim),cy-(gw*0.5)+shim,(base)])
        cube([ax+((extend-shim)*2),gw-(2*shim),(cz/2)]);
    for (i=[2:(ny-1)]) {
        if (i<ny) {
        translate([-(extend-shim),(i*cy)-(gw*0.5)+(shim),(base)])
        cube([ax+((extend-shim)*2),gw-(2*shim),(cz/2)]);
    }}};        
}
} */


//Walls and Channels
difference() { 
//Walls
if (baseprint==2 || baseprint==3  ||baseprint==0) {
union() {
    //Build X grid walls
    if (nx>1) {
        translate([cx-(gw*0.5)+shim,-(extend-shim),(base)])
        cube([gw-(2*shim),ay+((extend-shim)*2),(az+gh-(gz*2))])  ;
    for (i=[2:(nx-1)]) {
        if (i<nx) {
        translate([(i*cx)-(gw*0.5)+(shim),-(extend-shim),(base)])
        cube([gw-(2*shim),ay+((extend-shim)*2),(az+gh-(gz*2))]);
    }}};
    //Build Y grid walls 
    if (ny>1) { 
        translate([-(extend-shim),cy-(gw*0.5)+shim,(base)])
        cube([ax+((extend-shim)*2),gw-(2*shim),(az+gh-(gz*2))]);
    for (i=[2:(ny-1)]) {
        if (i<ny) {
        translate([-(extend-shim),(i*cy)-(gw*0.5)+(shim),(base)])
        cube([ax+((extend-shim)*2),gw-(2*shim),(az+gh-(gz*2))]);
    }}};        
}
} 

//Channels 

if (baseprint==3 || baseprint==0) {
union() {

    //Cut X grid wall channels
    if (nx>1) {
    //subtracts a vertical stack of 4 hexagonal prisms half a diameter apart
    for (m=[1:(ceil(1/prop)*2)]){
    //channels (gaps) in x as single long triangular prisms
    for (l=[1:nx]){
        translate([(l-0.5)*cx,0,(m*prop*cx*0.5)+gz+base+raise-3])
        rotate([-90,90,0])
        cylinder(h=ay,d=(prop*cy),$fn=6);        
            }
        }
    }
    if (ny>1) {
    //subtracts a vertical stack of 4 hexagonal prisms half a diameter apart
    for (m=[1:(ceil(1/prop)*2)]){
    //channels (gaps) in x as single long triangular prisms
    for (l=[1:ny]){
        translate([0,(l-0.5)*cy,(m*prop*cy*0.5)+gz+base+raise])
        rotate([0,90,0])
        cylinder(h=ax,d=(prop*cx),$fn=6);
            }
        }
    }
}
} 
/*
//Channels
if (baseprint==3 || baseprint==0) {
union() {
    //Cut X grid wall channels
    if (nx>1) {
    //subtracts a vertical stack of 4 hexagonal prisms half a diameter apart

    //channels (gaps) in x as single long triangular prisms
    for (l=[1:nx]){
        translate([(l-0.5)*cx,0,(prop*cx*0.5)+gz+base+raise])
        rotate([-90,90,0])
        #cylinder(h=ay,d=(prop*cy),$fn=6);        
            }

    }
    if (ny>1) {
    //subtracts a vertical stack of 4 hexagonal prisms half a diameter apart

    //channels (gaps) in x as single long triangular prisms
    for (l=[1:ny]){
        translate([0,(l-0.5)*cy,(prop*cx*0.5)+gz+base+raise])
        rotate([0,90,0])
        #cylinder(h=ax,d=(prop*cx),$fn=6);        
            }

    }
}
}*/


}
//Stirrer grid round
if (stirrer==1){
difference(){
    //Create block
    translate([-edge/2,-edge/2,bz*5])
    cube([ax+edge,ay+edge,mz],false);
    //Subtract bolt holes
    translate([-edge/2+bolte,-edge/2+bolte,bz*5-1])
    cylinder(h=mz+2,d=boltd,$fn=50);
    translate([ax+edge/2-bolte,-edge/2+bolte,bz*5-1])
    cylinder(h=mz+2,d=boltd,$fn=50);     
    translate([-edge/2+bolte,ay+edge/2-bolte,bz*5-1])
    cylinder(h=mz+2,d=boltd,$fn=50);
    translate([ax+edge/2-bolte,ay+edge/2-bolte,bz*5-1])
    cylinder(h=mz+2,d=boltd,$fn=50);
    //Subtract motor holes
    for (i=[1:nx]){
        for (j=[1:ny]){
            translate([(i-0.5)*cx,(j-0.5)*cy,bz*5-1])
            cylinder(h=mz+2,d=md,$fn=50);
        }
    }    
}
}
//Stirrer grid round
if (stirrer==2){
difference(){
    //Create block
    translate([-edge/2,-edge/2,bz*5])
    cube([ax+edge,ay+edge,mz],false);
    //Subtract bolt holes
    translate([-edge/2+bolte,-edge/2+bolte,bz*5-1])
    cylinder(h=mz+2,d=boltd,$fn=50);
    translate([ax+edge/2-bolte,-edge/2+bolte,bz*5-1])
    cylinder(h=mz+2,d=boltd,$fn=50);     
    translate([-edge/2+bolte,ay+edge/2-bolte,bz*5-1])
    cylinder(h=mz+2,d=boltd,$fn=50);
    translate([ax+edge/2-bolte,ay+edge/2-bolte,bz*5-1])
    cylinder(h=mz+2,d=boltd,$fn=50);
    //Subtract motor holes
    for (i=[1:nx]){
        for (j=[1:ny]){
            translate([(i-0.5)*cx,(j-0.5)*cy,bz*6-1
           ])
            cube([mx,my,mz],true);
            //cylinder(h=mz+2,d=md,$fn=50);
        }
    }  
    for (i=[1:nx]){
        for (j=[1:ny]){
            translate([(i-0.5)*cx,(j-0.5)*cy,bz*5-1])
            cylinder(h=mz+2,d=md,$fn=50);
        }
    }   
}
}

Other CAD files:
hardware/arena/bz_ca - arena + motor_mount.scad
hardware/arena/bz_ca HEX arena + motor_mount Bigger_with drain.scad
hardware/arena/pumps_clip.scad
hardware/magnet_mount/bz_ca - magnet_holder bigger.scad
hardware/magnet_mount/bz_ca - magnet_holder.scad
hardware/magnet_mount/bz_ca - magnet_mount.scad

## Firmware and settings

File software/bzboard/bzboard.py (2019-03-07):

'''
This is a minimal implementation of the bz_board python interface.
For some reason the full fledge implementation done by Kevin
was giving some problems we couldn't solve, so we are
doing this minimal implementation instead.

If you want better functionality, error handling,... check the other one

'''



import serial, time, json, os
from datetime import datetime
from random import randint, choice



class BZBoard:


    def __init__(self, port): # creates objects to pass through function for each self

        self.ser = serial.Serial(port, 9600, timeout=120)
        time.sleep(2) # serial docs recommend a wait just after connection
        self.ser.flush(); self.ser.flushInput(); self.ser.flushOutput();

        self.motors = { # [adafruit_shield, motor]
            "A1":[0,1],"A2":[0,2],"A3":[0,4],"A4":[0,3],"A5":[1,1],
            "B1":[1,2],"B2":[1,4],"B3":[1,3],"B4":[2,1],"B5":[2,2],
            "C1":[2,4],"C2":[2,3],"C3":[3,1],"C4":[3,2],"C5":[3,4],
            "D1":[3,3],"D2":[4,1],"D3":[4,2],"D4":[4,4],"D5":[4,3],
            "E1":[5,1],"E2":[5,2],"E3":[5,4],"E4":[5,3],"E5":[7,1]
            }
        # inactive but not off stirers for mixing

        # this matrix stores if the motors are enabled (1) or disabled (0)
        # before writting to serial we check this to not sent writes not needed
        self.matrix = { 
            "A1":0,"A2":0,"A3":0,"A4":0,"A5":0,
            "B1":0,"B2":0,"B3":0,"B4":0,"B5":0,
            "C1":0,"C2":0,"C3":0,"C4":0,"C5":0,
            "D1":0,"D2":0,"D3":0,"D4":0,"D5":0,
            "E1":0,"E2":0,"E3":0,"E4":0,"E5":0
            }
    

    def __del__(self):

        self.disable_all()
        self.ser.close()
        del self.ser


    def close(self):

        self.disable_all()
        self.ser.close()
        del self.ser


    def pattern_from_file(self, patternfile):

        with open(patternfile) as f:
            return json.load(f)


    def activate_motor(self, motor_code, direction=0, speed=100):
        ''' code as in A1 or C2 as marked in the actual board. See the dict motors'''

        shield, motor = self.motors[motor_code] # get shield and motor 
        
        # because sometimes we can send here a speed 0 to disable it
        # the following if will be longer than expected
        if self.matrix[motor_code] < 1 and speed > 0: # we need to activate it
            # The following line is a dirty trick. Some of the motors need to be
            # kickstarted at a higher speed
            command = "A%d M%d D%d S255\n" % (shield, motor, direction)
            # and then we send the desired speed
            command += "A%d M%d D%d S%d\n" % ( shield, motor, direction, speed )
            self.matrix[motor_code] = 1 # mark it as enabled
            self.ser.write(command.encode()) # encode helps program run 

        elif self.matrix[motor_code] < 1 and speed == 0: # we keep it disabled (it's off with 0 speed)
            pass

        elif self.matrix[motor_code] > 0 and speed > 0: # just update speed
            command = "A%d M%d D%d S%d\n" % ( shield, motor, direction, speed )
            self.ser.write(command.encode())

        elif self.matrix[motor_code] > 0 and speed == 0: # we disable it (on with no speed)
            self.disable_motor(motor_code)

        else:
            print("something bad happened when updating a motor") # broken


    def activate_all(self, direction=0, speed=100):

        for key in self.motors.keys(): # set to min stiring speed 
            self.activate_motor(key, direction, speed)
            self.ser.flush() #flush variables


    def activate_pattern(self, pattern, speed=None):

        for i in pattern:
            _, _, speed = self.motors[i] 

            if pattern[i] == 1:
                self.activate_motor(i, speed*2) # x5 before
            else:
                self.activate_motor(i, speed*0) # x1 before if motor is off speed off

    
    def activate_rand_all(self, filename):
        '''Activate a random pattern - each motor at a random speed - and append
        this random configuration to the end of the file filename'''

        # random 5*5 speed
        rand_speed = { 
                    "A1":randint(-10,10),"A2":randint(-10,10),"A3":randint(-10,10),"A4":randint(-10,10),"A5":randint(-10,10),
                    "B1":randint(-10,10),"B2":randint(-10,10),"B3":randint(-10,10),"B4":randint(-10,10),"B5":randint(-10,10),
                    "C1":randint(-10,10),"C2":randint(-10,10),"C3":randint(-10,10),"C4":randint(-10,10),"C5":randint(-10,10),
                    "D1":randint(-10,10),"D2":randint(-10,10),"D3":randint(-10,10),"D4":randint(-10,10),"D5":randint(-10,10),
                    "E1":randint(-10,10),"E2":randint(-10,10),"E3":randint(-10,10),"E4":randint(-10,10),"E5":randint(-10,10)
                    }

        # enable the motors with the random speeds
        for i in self.motors.keys():
            speed = rand_speed[i]
            
            if speed > 0:
                direction = 1
            else:
                direction = 0
            
            speed = abs(speed)*25
            
            self.activate_motor(i, direction, speed)

        self.save_pattern_in_json(rand_speed, filename)
        return rand_speed


    def repeat_rand(self, filename, inspeeds):
        ''' Repeats a random experiment and saves it into the corresponding
        json file'''
        
        for i in self.motors.keys():
            speed = inspeeds[i]
            
            if speed > 0:
                direction = 1
            else:
                direction = 0
            
            speed = abs(speed)*25
            
            self.activate_motor(i, direction, speed)

        self.save_pattern_in_json(inspeeds, filename)
        return inspeeds


    def activate_rand_multiple(self, filename):
        '''Activates only 1 motor at a random speed - and append
        this random configuration to the end of the file filename'''

        # first generate dict as before with all 0s
        speeds = { 
                    "A1":0,"A2":0,"A3":0,"A4":0,"A5":0,
                    "B1":0,"B2":0,"B3":0,"B4":0,"B5":0,
                    "C1":0,"C2":0,"C3":0,"C4":0,"C5":0,
                    "D1":0,"D2":0,"D3":0,"D4":0,"D5":0,
                    "E1":0,"E2":0,"E3":0,"E4":0,"E5":0
                    }

        num_oscilators = randint(1,26)
        for i in range(num_oscilators):
            random_motor = choice("ABCDE")+choice("12345") # choice is from random
            speed = randint(-10,10)

            # store the speed and activate the motor
            speeds[random_motor] = speed


        for motor in self.motors.keys():
            speed = speeds[motor]
        
            if speed > 0:
                direction = 1
            else:
                direction = 0
            
            speed = abs(speed)*25
            self.activate_motor(motor, direction, speed)

        self.save_pattern_in_json(speeds, filename)
        return speeds
  

    def activate_rand_column(self, filename):
        '''activates a random column at a random speed. All the motors in that
        column will be at the same speed'''

        # first generate a dict as before with all 0s
        speeds = { 
                    "A1":2,"A2":2,"A3":2,"A4":2,"A5":2,
                    "B1":2,"B2":2,"B3":2,"B4":2,"B5":2,
                    "C1":2,"C2":2,"C3":2,"C4":2,"C5":2,
                    "D1":2,"D2":2,"D3":2,"D4":2,"D5":2,
                    "E1":2,"E2":2,"E3":2,"E4":2,"E5":2
                    }

        random_column = choice("ABCDE")
        #speed = randint(-10,10)
        speed = choice([-8,8])

        # store the new speed in all the motors of the column generated
        for row in range(1,6):
            motor = random_column+str(row)
            speeds[motor] = speed

        for motor in self.motors.keys():
            speed = speeds[motor]
        
            if speed > 0:
                direction = 1
            else:
                direction = 0
            
            speed = abs(speed)*25
            self.activate_motor(motor, direction, speed)

        self.save_pattern_in_json(speeds, filename)
        return speeds

    def save_pattern_in_json(self, pattern, filename):
        '''given a dict with all the motors keys and their speeds, and a filename
        it will append this pattern into that filename with a timestamp
        This function was created for the RNN experiments'''
    
        
        # we will use time as keys in the dict
        exp_time = datetime.now().strftime('%Y-%m-%d_%H:%M:%S')
        filename = filename +'.json'
        # new data entry for the dict
        new_dict = { exp_time : pattern}
        
        # if the file does not exist, meaning its the first experiment
        if os.path.isfile(filename) is False:
            data = new_dict
        
        else:
            # load the previous json to update with new data
            with open(filename) as f:
                data = json.load(f)
                data.update(new_dict)

        # update the json
        with open(filename, 'w') as f:
            json.dump(data, f)


    def disable_motor(self, motor_code):

        shield, motor = self.motors[motor_code]
        command = "A%d M%d D0 S0\n" % ( shield, motor )

        if self.matrix[motor_code] > 0: # so it was enabled
            self.ser.write(command.encode())
            self.matrix[motor_code] = 0 # mark it disabled


    def disable_all(self):

        for key in self.motors.keys():
            self.disable_motor(key)



if __name__ == "__main__":

    b = BZBoard("/dev/ttyACM1")

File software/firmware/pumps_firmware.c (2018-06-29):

/*
 * commands are like P_ M_ C_ D_ S_ E_
 * Each argument starts with a capital letter, followed by numbers (value of arg), no space
 * Each argument is separated by 1 space
 * P means pump, identifies the pump. At the moment it goes from 0 to 6
 * M means motor, identifies motor inside the P declared before. it is 0 or 1, for valve or plunger
 * C means code that identifies the task. Once the task is finished, this code will be send to the Serial
 * D means direction, up or down. 0 or 1
 * S means speed, which is actually the ms per pulse. We usually use values between 20 to 2000
 * E means steps, number of steps. Needs to be bigger than 0. With triconts 100k is full plunger
 * This firmware DOESNT CHECK ANYTHING, make the checks in the code that sends the commands here
 * For example, if you are rotating motor P0 M0, and while its rotating, you sends a new command to the same motor
 * this firmware is likely to fuck itself.
 * An example of command would be: P0 M1 D0 C123 S50 E50000
 *
 * Juan M Parrilla, Cronin group
*/ 


#define MOTORS_PER_PUMP 2
#define BUFFER_SIZE 200

struct Motor
{
	/* INPUTS */
	long pin_en;
	long pin_step;
  long pin_dir;

	/* STATE */
	long msec_per_pulse;
	long remaining_steps;
	long next_state; /* controls pin_step, so it will be high or low */
	long remaining_step_ms;
	long task_code;
};

struct Pump
{
	Motor motors[2]; /* 0 is plunger, 1 is valve */
};

Pump pumps[] = {
	// PX_ENABLE, PX_STEP, PX_DIR -- VX_ENABLE, VX_STEP, VX_DIR
	{ { {4, 3, 2}, {7, 6, 5} } }, 		// pump 1
	{ { {54, 55, 56}, {57, 58, 59} } }, // pump 2
	{ { {60, 61, 62}, {63, 64, 65} } }, // pump 3
	{ { {66, 67, 68}, {69, 53, 52} } }, // pump 4
	{ { {18, 17, 16}, {26, 24, 22} } },	// pump 5
	{ { {13, 12, 11}, {10, 9, 8} } }, 	// pump 6
	{ { {32, 30, 28}, {38, 36, 34} } }, 	// pump 7
	{ { {14, 15, 19}, {20, 21, 23} } } 	// pump 8
};

int n_pumps = sizeof(pumps)/sizeof(pumps[0]);

int read_command(char *buffer) {

	static int pos = 0;
	int rpos;

	if (Serial.available() > 0) {

		char readch = Serial.read();

		switch (readch) {

			case '\n':
				rpos = pos;
				pos = 0; // Reset position index ready for next time
				return rpos;

			default:

				if (pos < BUFFER_SIZE -1) {
					buffer[pos++] = readch;
					buffer[pos] = '\0';
				} else {
					Serial.println("666"); //buffer overflow
				}
		}
	}
	// no end line or char found, return -1
	return -1;

}


void parse_command(char* command) 
{
	char* parameter;
	parameter = strtok(command, " ");

	while (parameter != NULL) {

		Pump *pump;
		Motor *motor;
		long pumpid, motorid, code, dir, sp, steps;

		switch(parameter[0]) {

			case 'P':
				pumpid = strtol(parameter+1, NULL, 10);
				pump = &pumps[pumpid];
				break;

			case 'M':
				motorid = strtol(parameter+1, NULL, 10);
				motor = &pump->motors[motorid];
				digitalWrite( motor->pin_en, LOW ); //enable motor
				break;

			case 'C':
				code = strtol(parameter+1, NULL, 10);
				motor->task_code = code;
				break;

			case 'D':
				dir = strtol(parameter+1, NULL, 10);
				if (dir == 0) {
					digitalWrite( motor->pin_dir, LOW );
				} else {
					digitalWrite( motor->pin_dir, HIGH );
				}
				break;

			case 'S':
				sp = strtol(parameter+1, NULL, 10);
				motor->msec_per_pulse = sp;
				motor->remaining_step_ms = sp;
				break;

			case 'E':
				steps = strtol(parameter+1, NULL, 10);
				motor->remaining_steps = steps;
				if (steps <= 0) {
					Serial.println(motor->task_code);
				}
				break;
		}
		parameter = strtok(NULL, " ");
	}
	
	for (int x=0; x < BUFFER_SIZE; x++)
		command[x] = '\0';
	
}

void setup() 
{
	Serial.begin(115200);
	Serial.flush();

	for (int pumpi = 0; pumpi < n_pumps; pumpi++) {
		Pump *pump = &pumps[pumpi];
		for (int motori = 0; motori < MOTORS_PER_PUMP; motori++) {
			Motor *motor = &pump->motors[motori];
			motor->remaining_step_ms = 0;
			motor->remaining_steps = 0;
			motor->next_state = 1;
			pinMode(motor->pin_en, OUTPUT);
			pinMode(motor->pin_dir, OUTPUT);
			pinMode(motor->pin_step, OUTPUT);
			digitalWrite(motor->pin_en, HIGH); // HIGH is disabled
		}
	}
}

void loop() 
{
	static char buffer[BUFFER_SIZE];

	if (read_command(buffer) > 0) {
		parse_command(buffer);
	}

	long msec = 2147483647; // max long
	for (int pumpi = 0; pumpi < n_pumps; pumpi++) {
		Pump *pump = &pumps[pumpi];
		for (int motori = 0; motori < MOTORS_PER_PUMP; motori++) {
			Motor *motor = &pump->motors[motori];
			if (motor->remaining_steps > 0) {
				msec = min(msec, motor->remaining_step_ms);
			}
		}
	}

	if (msec < 2147483647)
		delayMicroseconds(msec);

	for (int pumpi = 0; pumpi < n_pumps; pumpi++) {
		Pump *pump = &pumps[pumpi];
		for (int motori = 0; motori < MOTORS_PER_PUMP; motori++) {
			Motor *motor = &pump->motors[motori];
			if (motor->remaining_steps > 0) {
				motor->remaining_step_ms -= msec;
				if ( (motor->remaining_step_ms <= 0) ) {
					/* This motor is ready for the next step */
					digitalWrite(motor->pin_step, motor->next_state);
					motor->next_state = !motor->next_state;
					motor->remaining_step_ms = motor->msec_per_pulse;
					motor->remaining_steps--;
					if (motor->remaining_steps <= 0) { // motor finished task
						digitalWrite( motor->pin_en, HIGH); // disable motor
						motor->remaining_step_ms = 0;
						motor->remaining_steps = 0;
						motor->msec_per_pulse = 0;
						Serial.println(motor->task_code);
					}
				}
			}
		}
	}
}

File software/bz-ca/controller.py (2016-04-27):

"""
    coding: UTF-8

    controller.py

    Created 25/04/2016
    Kevin Donkers, The Cronin Group, University of Glasgow

    Control BZ-CA platform
"""

# system modules
import time, math
import json

# additional modules
import serial
import cv2, cv

# project modules
from commanduino.commandhandler import SerialCommandHandler

# default parameters


DEFAULT_IO_BAUDRATE = 9600
DEFAULT_IO_TIMEOUT = 1
DEFAULT_IO_DELIM = ','
DEFAULT_IO_TERM = ';'


class ControllerIO(object):

    def __init__(self, port, baudrate=DEFAULT_IO_BAUDRATE, timeout=DEFAULT_IO_TIMEOUT, delim=DEFAULT_IO_DELIM, term=DEFAULT_IO_TERM):
        self.logger = logging.getLogger(self.__class__.__name__)

        self.open(port, baudrate, timeout, delim, term)
        # is this necessary?
        self.cmdHdl.add_default_handler(defaultPrint)
        self.cmdHdl.start()

    @classmethod
    def from_config(cls, io_config):
        port = io_config['port']

        if 'baudrate' in io_config:
            baudrate = io_config['baudrate']
        else:
            baudrate = DEFAULT_IO_BAUDRATE

        if 'timeout' in io_config:
            timeout = io_config['timeout']
        else:
            timeout = DEFAULT_IO_TIMEOUT

        if 'delim' in io_config:
            delim = io_config['delim']
        else:
            delim = DEFAULT_IO_DELIM

        if 'term' in io_config:
            term = io_config['term']
        else:
            term = DEFAULT_IO_TERM

        return cls(port, baudrate, timeout, delim, term)

    @classmethod
    def from_configfile(cls, io_configfile):
        with open(io_configfile) as f:
            return cls.from_config(json.load(f))

    def __del__(self):
        self.close()

    def __exit__(self, exc_type, exc_value, traceback):
        self.close()

    def open(self, port, baudrate=DEFAULT_IO_BAUDRATE, timeout=DEFAULT_IO_TIMEOUT, delim=DEFAULT_IO_DELIM, term=DEFAULT_IO_TERM):
        self.cmdHdl = SerialCommandHandler(port, baudrate, timeout, delim, term)

    def close(self):    #check this is how to close
        self.cmdHdl.stop()
        self.cmdHdl.join()

    # def flushInput(self):
    #     self._serial.flushInput()

    def write(self, packet):
        str_to_send = packet.to_string()
        self.cmdHdl.write(str_to_send)

    def defaultPrint(self, cmd):
        print cmd
    
    # def readline(self):
    #     msg = self._serial.readline()
    #     if msg:
    #         self.logger.debug("Received {}".format(msg))
    #         return msg
    #     else:
    #         raise PumpIOTimeOutError

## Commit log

2016-05-03 add functions to load motor lookup table from config file
2016-05-03 made more sense to load motor lookup table with io parameters from config file
2016-05-05 forgot to use self.motors
2016-05-05 table of EVOPROG board pins and their corresponding pwm [shield,pin] combo
2016-05-05 comment on format of motor dict
2016-05-05 better not to load anything if config contains no motors dict
2016-05-05 motor activation and deactivation commands added
2016-05-05 set frequency of pwm in __init__
2016-05-10 example added of how to run pattern of motors
2016-06-30 parts_list.csv added
    [part_links.csv]
2016-07-01 latest magnet mount
    [bz_ca - magnet_holder.scad, bz_ca - magnet_holder.stl, bz_ca - magnet_mount.stl]
2016-07-01 minimum speeds spreadsheet
    [min_speeds.ods]
2016-10-19 Changing the prints from python2 to python3
2016-10-19 Adding commandhandler directly here, so people won't spend 1 hour like I just did linking libs
    [bzboard.py]
2016-11-10 Changing the baudrate from 112500 to 9600, because in all the adafruit examples I have seen with this shield they use 9600 Just in case this has some sort of impact in the platform becoming unrespons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
2016-11-10 Continuing integration into python3 which is fully working now. Rolling back from 9600 to 115200. For some reason 9600 did not work
    [bzboard.py]
2017-01-19 Adding the changes suggested by Jonathan. It does not fix the fact that the platform becomes uresponsive, but now we know for sure it is not an arduino problem, because serial commands go in a out ev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
2017-01-19 Minimal firmware copying adafruit test file, plus basic serial read. It does work so far, it doesn't get stuck, plus the two motors which were not working before and now working.
    [bz_firmware.ino]
2017-01-25 Arduino forced to put the file inside a folder with the same name
2017-03-08 No big changes with respect to the previous commit. Just debbuging. The main thing is that we added a serial flush after serial write in the python script, because there was some sort of buffer probl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
    [bz_firmware.ino, bzboard.py]
2017-03-08 Because sadly we are not using now the implementation Kevin did, we have removed it from the repo and kept only the one we use now. In any case, the old implementation should be saved here in the Git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
2017-03-09 Adding min speed to motors
2017-03-13 Adding new patterns in order to control it row by row. In the python file the only difference are the speeds used for each motor. We try to get them working nicely, but it is really difficult.
2017-04-11 Adding the new legs for the platform
    [arena_legs.scad]
2017-04-18 Various changes to stl files and openscad designs
    [bz_ca - arena + motor_mount Bigger.scad, bz_ca - arena - deep.stl, bz_ca - arena - holes.stl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]
2017-04-21 Trying to make the spacing a bit bigger so that it doesnt touch the magnet mounts
    [arena_legs.scad]
2017-05-04 Calcuting the speed for each motor so that they go roughly at 90rpm at 6v
2017-05-08 renaming play cam to record cam, and adding a timer
2017-05-12 Getting better framerate when recording camera, and tweaking the motors trying to get most of them at a similar speed
2017-06-12 Adding a new data representation which is like the HSV 3D histogram, but it also uses the average color of the last N frames.
2017-07-21 Using an in-built python function to calculate the average color per frame instead of using our home made function
2017-09-18 Removing a dat file not needed anymore. Adding a new file to calculate the direction of the bz wave using moments from opencv. Nothing interesting changed in the scad file
    [bz_ca - arena + motor_mount Bigger.scad]
2017-10-11 Fixing a stupid bug when I used a wrong variable name
    [bzboard.py]
2018-01-26 Adding scad files for the new grid with different cell shapes, and also for a clip where to attach tubes to automate the platform
    [bz_ca HEX arena + motor_mount Bigger_with drain.scad, pumps_clip.scad]
2018-01-30 Adding firmware and python script to control pumps, because we want to automate the BZ experiments
2018-01-31 Second version of the pumps clip to attach tubes to the BZ platform
    [bz_ca HEX arena + motor_mount Bigger_with drain.scad, pumps_clip.scad]
2018-02-05 Adding the new SCAD designs
    [arena_legs.scad, bz_ca - arena + motor_mount Bigger.scad, bz_ca HEX arena + motor_mount Bigger_with drain.scad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]
2018-02-06 Removing unused pumps
2018-02-07 fixing a bug that happened when the same pump was executed twice in a run before finishing. Now that should be working
2018-02-08 Renamed pumpsctl to all lower case
2018-02-09 Divided the pump in in the main experiment between 3 steps, because otherwise it was slow because the arduino cannot keep up
2018-02-16 Adding clip for tubes to basic arena
    [bz_ca - arena + motor_mount Bigger.scad, bz_ca HEX arena + motor_mount Bigger_with drain.scad, pumps_clip.scad]
2018-06-29 Not important changes. Ignore
    [bz_ca - arena + motor_mount Bigger.scad]
2018-06-29 Changing pumps_firmware so it is kept. I deleted it by mistake
    [pumps_firmware.c]
2018-07-13 Having problems in time map with frame rates...
2018-07-13 Time map starting from first frame
2018-10-01 Commiting everything before paper
    [arena_legs.scad, bz_ca - arena + motor_mount Bigger.scad, bz_ca HEX arena + motor_mount Bigger_with drain.scad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]
2018-10-24 Update pumpsctl.py to save volumes to file and load them in
2018-10-24 New experiment with AND OR in the same board
2018-10-24 Update pumpsctl.py save volume resets to file
2018-10-24 Update pumpsctl.py added path hack from master
2018-10-29 Update pumpsctl.py can reset all volumes via prompt
2018-10-30 Cleaning fixing code from AQ
    [bzboard.py]
2018-10-30 Changes in robolab. Problem with pumps and sync with new pickle volume control file
2018-11-01 Using json to save the random patterns. Before was not working. This is not tested yet
    [bzboard.py]
2018-11-02 Fixing loading and dumping random motor configs into json not tested in robot yet
    [bzboard.py]
2018-11-02 Update pumpsctl.py quits if not enough liquid to run
2018-11-05 Adding a lock so that the functions that checks for volumes can only be accessed one by one thread
2018-11-06 Replace pumpsctl.py
2018-11-09 Replace bzboard.py added new function
    [bzboard.py]
2018-11-09 Replace automatedBZnonrand.py called new function from BZ board
2018-11-13 Update pumpsctl.py move all volume stuff to volctl
2018-11-13 Update pumpsctl.py missed importing VolCtl
2018-11-13 Replace pumpsctl.py bug fix
2019-01-31 BZ motors firmware has been updated to use adafruit motor shield instead of our home made PCB
2019-02-04 BZ working with new PCBs
2020-02-13 Removing old file from Kevin
    [min_speeds.ods]
